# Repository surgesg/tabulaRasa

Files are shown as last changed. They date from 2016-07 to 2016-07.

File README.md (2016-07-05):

# tabulaRasa

The tabulaRasa is a digital wavetable oscillator with voltage control of frequency, waveform selection, 
and the amount of interpolation between waveforms. 
The tabulaRasa consists of two components: a hardware synthesis module which can integrate
into a modular synth system, and a software application which allows the user to create their own custom waveforms. 
These waveforms are then transferred from the computer to the tabulaRasa module through a standard SD card slot.

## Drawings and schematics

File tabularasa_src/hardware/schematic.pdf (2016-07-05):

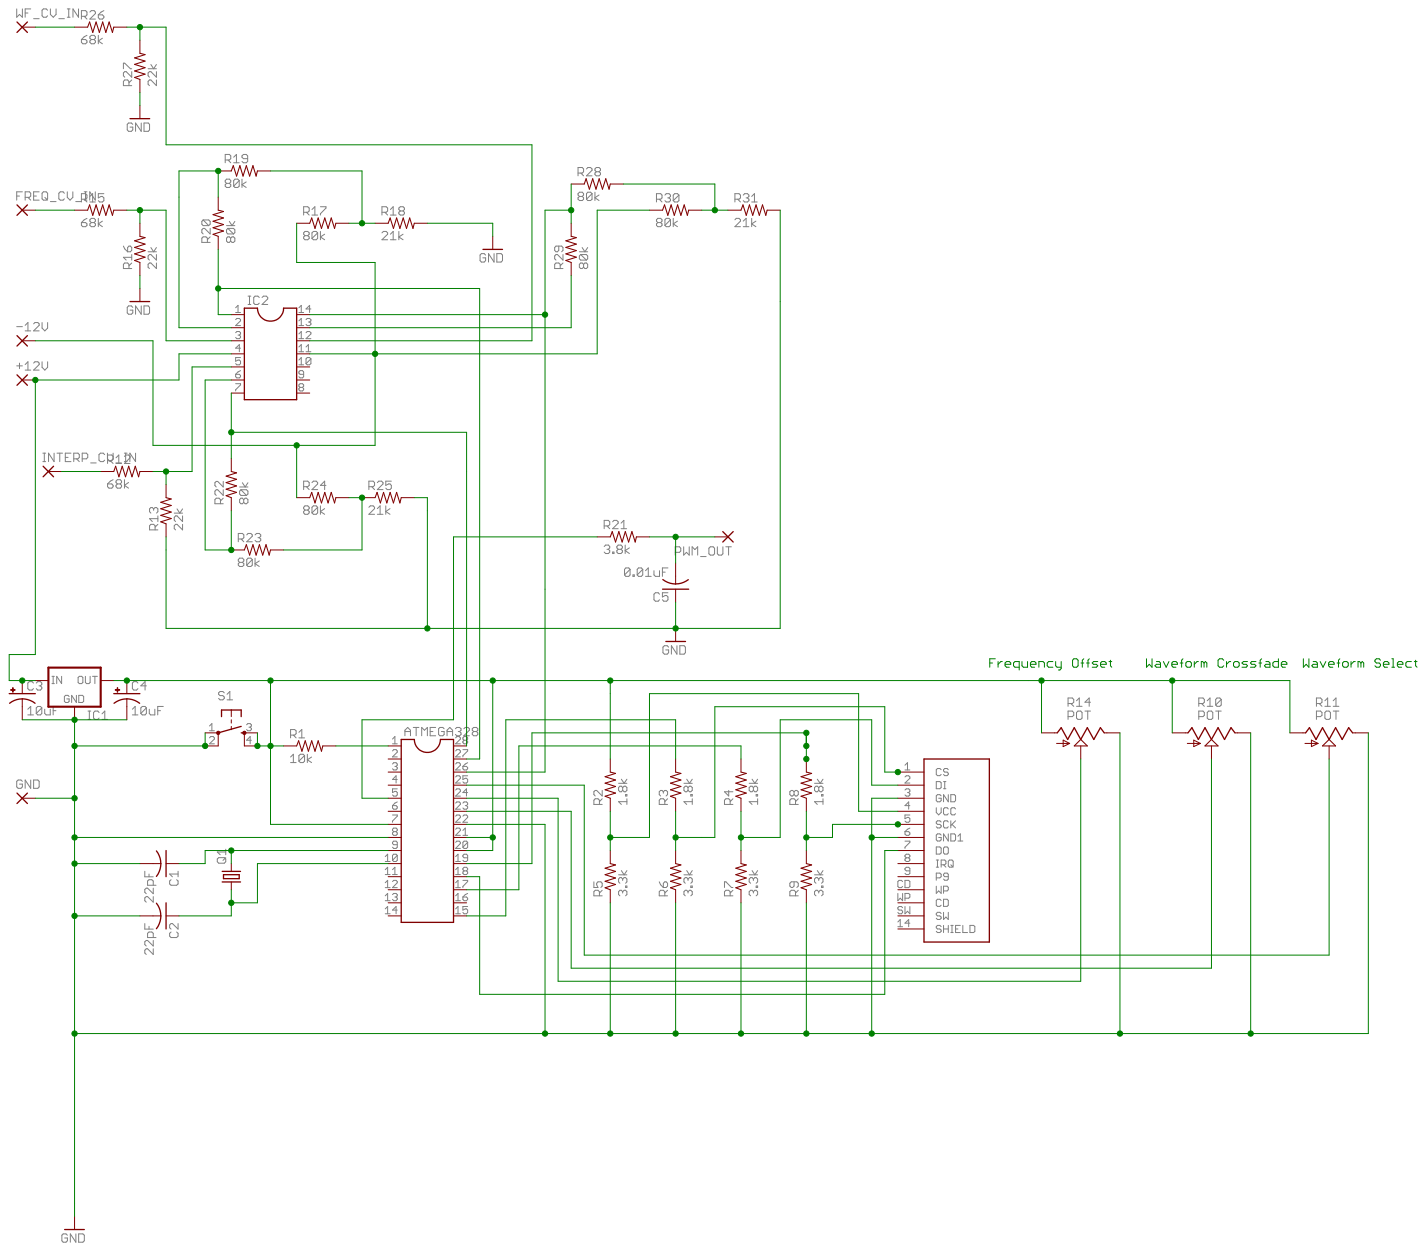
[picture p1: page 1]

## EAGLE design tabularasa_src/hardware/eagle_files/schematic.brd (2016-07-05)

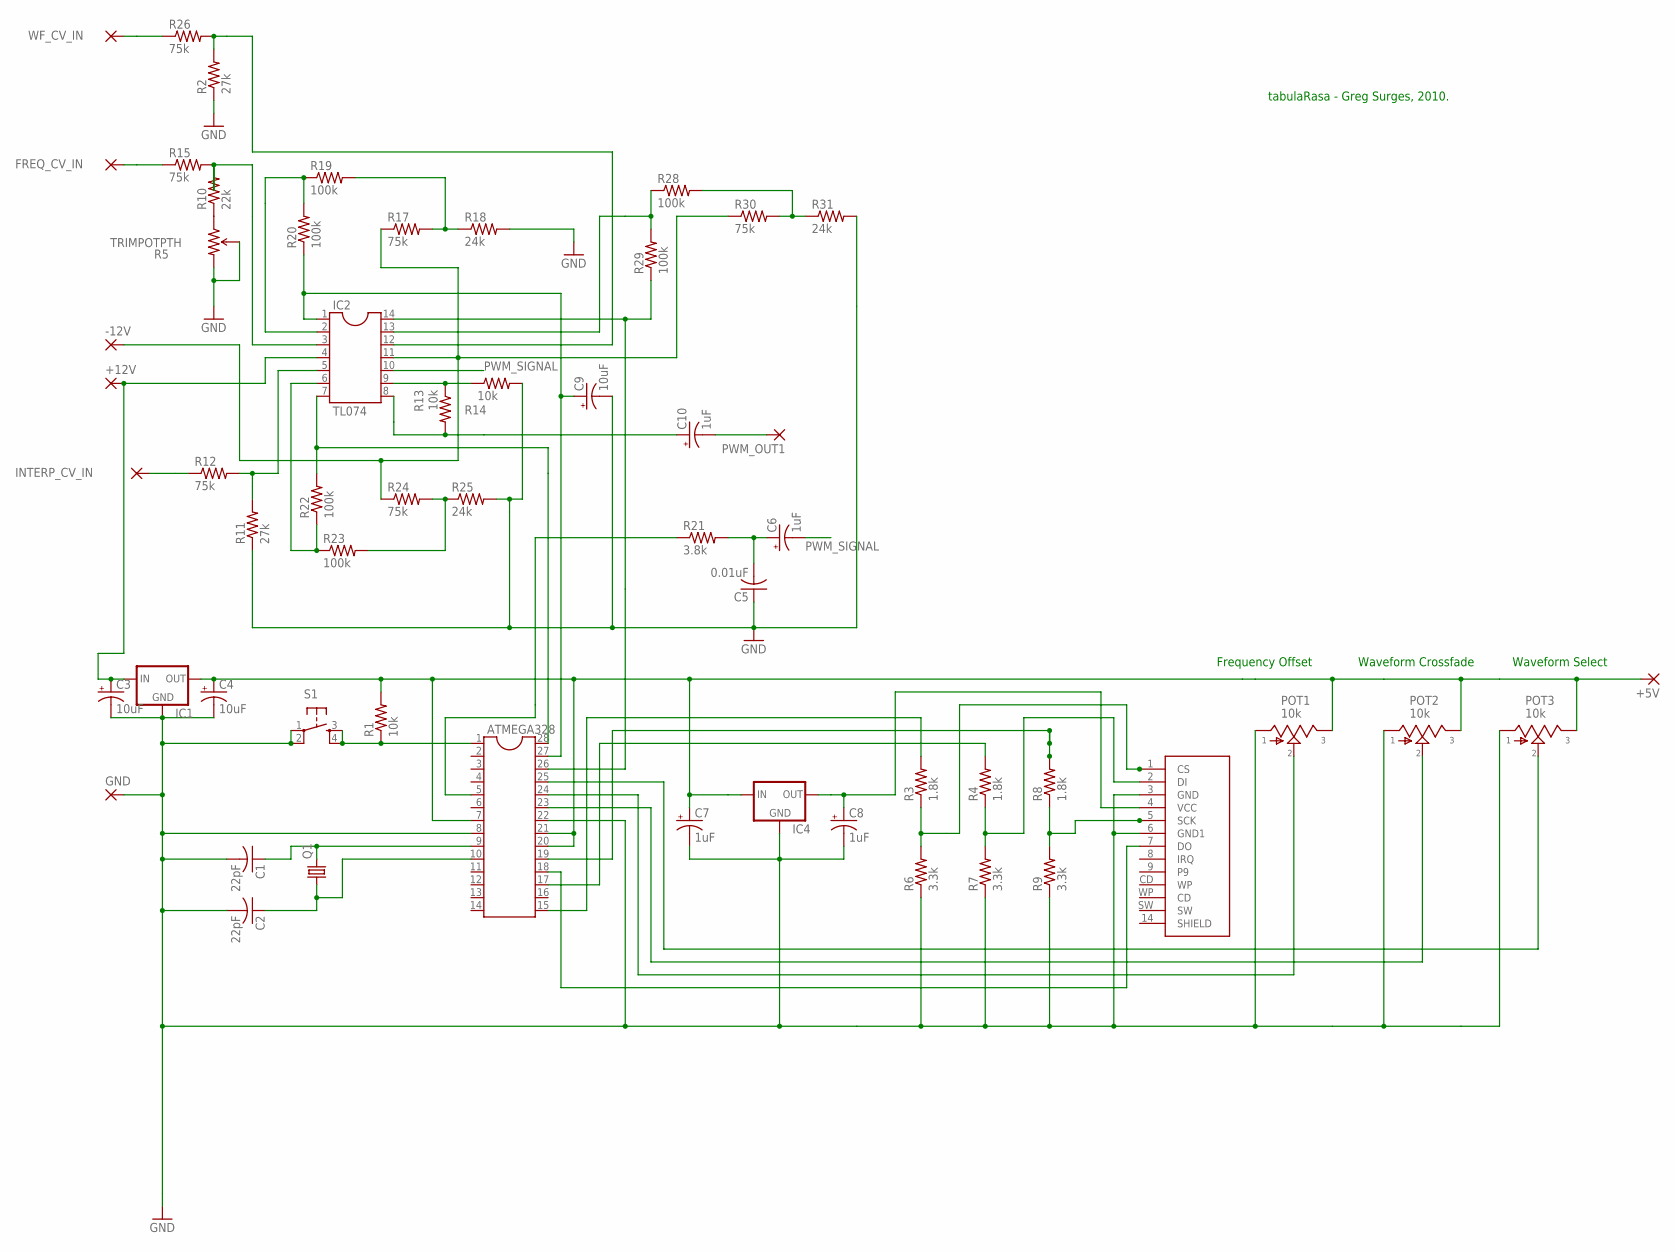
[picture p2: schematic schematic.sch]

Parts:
+5V, +12V: 3,81/1,4
-12V: 3,81/1,4
ATMEGA328: DIL28-3
C1, C2: 22pF; C050-025X075
C3, C4, C9: 10uF; E2,5-6
C5: 0.01uF; C050-025X075
C6, C7, C8, C10: 1uF; E2,5-6
FREQ_CV_IN: 3,81/1,4
GND: 3,81/1,4
IC1: V_REG_78XXSIDE; 78XXL
IC2: TL074; DIL14
IC4: MCP1700INLINE; TO92-INLINE
INTERP_CV_IN: 3,81/1,4
POT1, POT2, POT3: 10k; 16MM-PCB-MOUNT
PWM_OUT1: 3,81/1,4
Q1: CRYSTALHC49US; HC49US
R1, R13, R14: 10k; 0411/12
R2, R11: 27k; 0411/12
R3, R4, R8: 1.8k; 0411/12
R5: TRIMPOTPTH; TRIM_POT_PTH
R6, R7, R9: 3.3k; 0411/12
R10: 22k; 0411/12
R12, R15, R17, R24, R26, R30: 75k; 0411/12
R18, R25, R31: 24k; 0411/12
R19, R20, R22, R23, R28, R29: 100k; 0411/12
R21: 3.8k; 0411/12
S1: TAC_SWITCHPTH; TACTILE-PTH
U$1: SD_CARD_SOCKETSD; SD-MMC_SOCKET-PP
WF_CV_IN: 3,81/1,4

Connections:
GND: ATMEGA328.8, ATMEGA328.22, C1.2, C2.2, C3.-, C4.-, C5.1, C7.-, C8.-, C9.-, GND.1, IC1.GND, IC4.1 (GND), POT1.1, POT2.1, POT3.1, R2.1, R5.2 (WIPER), R5.3 (CW), R6.1, R7.1, R9.1, R11.1, R14.2, R18.2, R25.2, R31.2, S1.1, S1.2, U$1.3 (GND), U$1.6 (GND1)
unnamed: C8.+, IC4.3 (OUT), U$1.4 (VCC)
unnamed: +5V.1, ATMEGA328.7, ATMEGA328.20, ATMEGA328.21, C4.+, C7.+, IC1.OUT, IC4.2 (IN), POT1.3, POT2.3, POT3.3, R1.2
unnamed: R3.1, R6.2, U$1.1 (CS)
unnamed: ATMEGA328.1, R1.1, S1.3, S1.4
unnamed: R4.1, R7.2, U$1.2 (DI)
unnamed: ATMEGA328.9, C1.1, Q1.2
unnamed: ATMEGA328.10, C2.1, Q1.1
unnamed: INTERP_CV_IN.1, R12.1
unnamed: ATMEGA328.18, U$1.7 (DO)
unnamed: R5.1 (CCW), R10.1
unnamed: R8.1, R9.2, U$1.5 (SCK)
unnamed: ATMEGA328.15, R3.2
unnamed: ATMEGA328.24, POT1.2
unnamed: ATMEGA328.17, R4.2
unnamed: ATMEGA328.19, R8.2
unnamed: ATMEGA328.23, POT2.2
unnamed: ATMEGA328.25, POT3.2
unnamed: +12V.1, C3.+, IC1.IN, IC2.4
unnamed: IC2.2, R19.1, R20.2
unnamed: ATMEGA328.28, IC2.7, R22.2
unnamed: IC2.6, R22.1, R23.1
unnamed: FREQ_CV_IN.1, R15.1
unnamed: IC2.9, R13.1, R14.1
unnamed: ATMEGA328.27, C9.+, IC2.1, R20.1
unnamed: R17.2, R18.1, R19.2
unnamed: R28.2, R30.2, R31.1
unnamed: ATMEGA328.5, R21.1
unnamed: C5.2, C6.+, R21.2
unnamed: R23.2, R24.2, R25.1
unnamed: R26.1, WF_CV_IN.1
unnamed: IC2.12, R2.2, R26.2
unnamed: IC2.13, R28.1, R29.2
unnamed: ATMEGA328.26, IC2.14, R29.1
unnamed: -12V.1, IC2.11, R17.1, R24.1, R30.1
unnamed: C10.-, PWM_OUT1.1
unnamed: IC2.3, R10.2, R15.2
unnamed: IC2.5, R11.2, R12.2
OUTPUT: C10.+, IC2.8, R13.2
PWM_SIGNAL: C6.-, IC2.10

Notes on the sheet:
Frequency Offset
Waveform Crossfade
Waveform Select
tabulaRasa - Greg Surges, 2010.

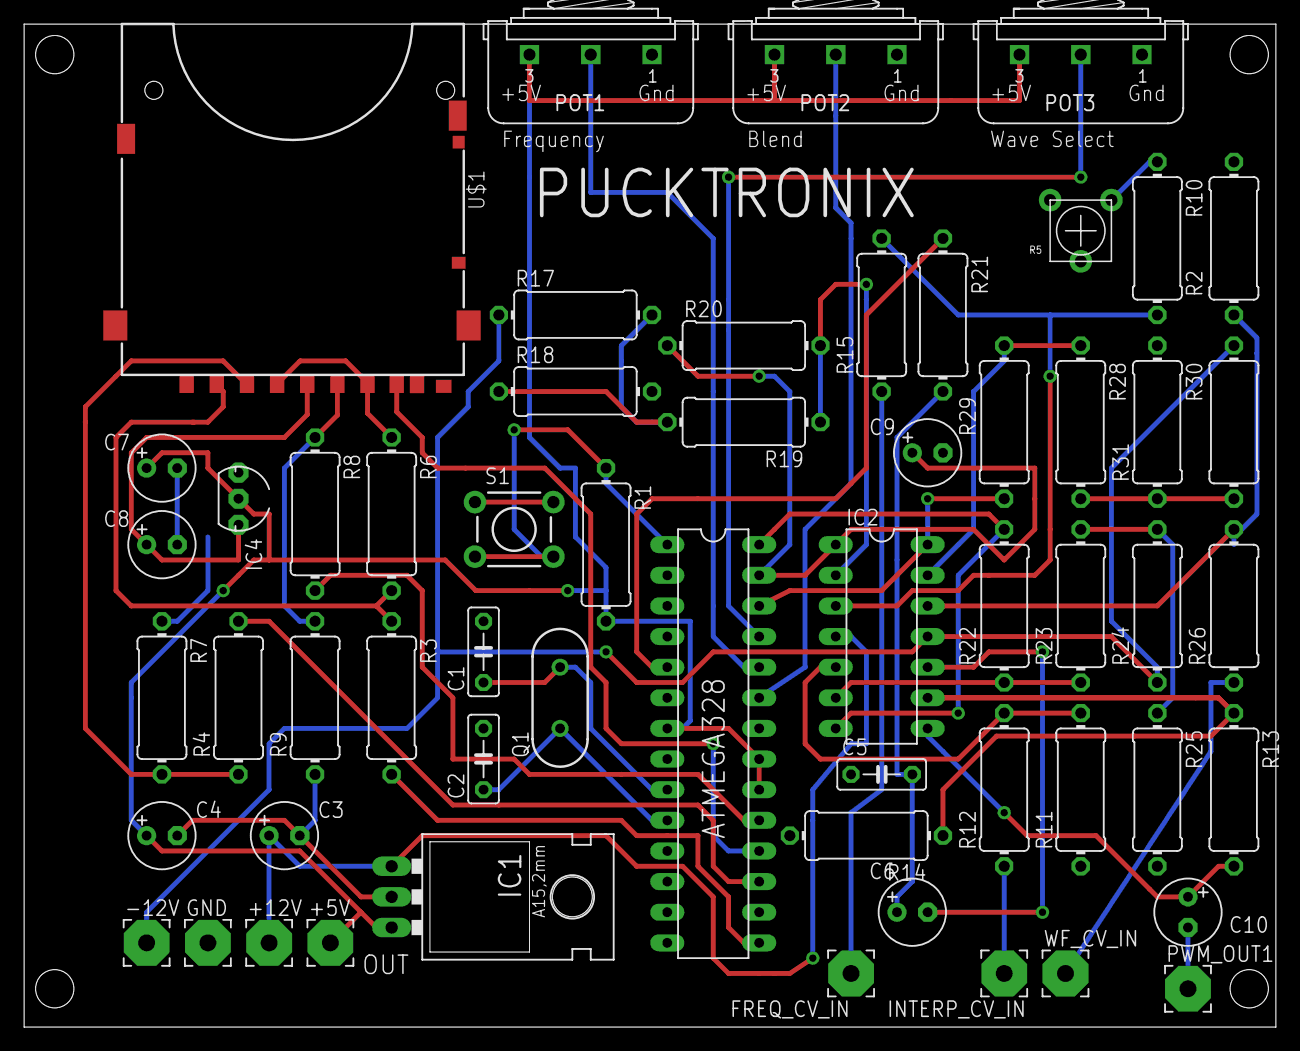
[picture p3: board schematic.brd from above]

Board: 2 copper layers, 103.8 x 83.2 mm, 57 parts (0 on the bottom side), 40 nets.

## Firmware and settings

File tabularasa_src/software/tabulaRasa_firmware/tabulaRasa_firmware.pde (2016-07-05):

/*************************************************
 * tabulaRasa_Arduino_PWM.pde
 * last updated 3.12.2011 - greg surges surgesg@gmail.com
 * 
 * atmega328 (w/ arduino bootloader) mcu code for use in tabulaRasa wavetable oscillator
 * 
 * reads "data.dat" from sd card - produced by tabulaRasa Editor Software
 * 
 * some code borrowed from Adrian Freed
 * 
 * todo: 
 * continued commenting
 * internal pullup / down resistors on analog pins
     
    This file is part of tabulaRasa.

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
    You should have received a copy of the GNU General Public License
    along with tabulaRasa.  If not, see <http://www.gnu.org/licenses/>.
*/
 
 *************************************************/

#include <avr/io.h>
#include <avr/interrupt.h>

#include <SD.h>

#define PWM_PIN       3
#define PWM_VALUE_DESTINATION     OCR2B
#define PWM_INTERRUPT TIMER2_OVF_vect

Sd2Card card;
SdVolume volume;
SdFile root;
SdFile file;

/*** variables from Adrian Freed ***/
const unsigned int LUTsize = 1<<8; 
const int timerPrescale=1<<9;
const int fractionalbits = 16; 
uint8_t predivide = 8;
/******************************/

byte waveform[256 * 2]; // allocate RAM to store the currently used waveforms
int8_t waveformSlot = 0; // the current waveform, corresponding to the slots in the Editor App
int8_t previousWaveformSlot = 0;
byte finalWaveform[256]; // the composite waveform, after computing crossfade 

int8_t outputvalue = 0; // the sample written out to PWM
float frequency; // oscillation frequency in Hz.
int8_t counter = 0; // limit the rate at which slot and crossfade input adc is read

float frequencyInputs = 0;
float freqCV = 0;
int slotInputs = 0;
float slotCV = 0;
float fadeInputs = 0;
float fadeCV = 0;
float midpoint = 0;
float range = 0;

// store error strings in flash to save RAM
#define error(s) error_P(PSTR(s))
void error_P(const char* str) {
  PgmPrint("error: ");
  SerialPrintln_P(str);
  if (card.errorCode()) {
    PgmPrint("SD error: ");
    Serial.print(card.errorCode(), HEX);
    Serial.print(',');
    Serial.println(card.errorData(), HEX);
  }
  while(1);
}

struct oscillator
{
  uint32_t phase;
  int32_t phase_increment;
} 
o1;

/*** following 2 functions from Adrian Freed ***/
unsigned long phaseinc(float frequency_in_Hz)
{
  return LUTsize *(1l<<fractionalbits)* frequency_in_Hz/(F_CPU/timerPrescale);
}

void initializeTimer() {
  TCCR2A = _BV(COM2B1)  | _BV(WGM21) | _BV(WGM20);
  TCCR2B = _BV(CS20);
  TIMSK2 = _BV(TOIE2);
  pinMode(PWM_PIN,OUTPUT);
}
/**********************************************/


void setup()
{
  pinMode(A0, INPUT);
  pinMode(A1, INPUT);
  digitalWrite(A1, HIGH);
  pinMode(A2, INPUT);
  pinMode(A3, INPUT);
  pinMode(A4, INPUT);
  digitalWrite(A4, HIGH);
  pinMode(A5, INPUT);
  if (!card.init(SPI_FULL_SPEED, 9)) error("card.init failed");
  if (!volume.init(&card)) error("volume.init failed");
  if (!root.openRoot(&volume)) error("openRoot failed"); 
  if (file.open(&root, "data.dat", O_READ)) {
    //  Serial.println("Opened data.dat");
  }
  file.read(waveform, 256 * 2);
  o1.phase = 0;
  o1.phase_increment = 0;
  initializeTimer();
}

void loop() {
  /*****************************************************************************
   * frequency is modulated by both pot and cv input, which are summed - each covering half the potential range
   * necessary to do it this way to maintain v/octave control of pitch.
   *****************************************************************************/
  analogRead(A1); // toss this value for accuracy
  frequencyInputs = analogRead(A1) / 102.3;
  analogRead(A4); // toss this value for accuracy
  frequencyInputs += analogRead(A4) / 102.3;
  
  frequencyInputs = pow(2, frequencyInputs); // v/octave pitch
  frequency = (frequency * 0.8) + (frequencyInputs * 0.2); // compute a moving average, to minimize freq jitter
  o1.phase_increment = phaseinc(frequency);

  // the other controls are only read every 50th cycle through loop() because they are less frequency dependent
  // hopefully this allows for a higher rate of FM

  if(counter >= 50){
    /*****************************************************************************  
     * the midpoint of the waveform select is set by the potentiometer.
     * the potentiometer setting also establishes the range that the cv input is allowed to cover.
     * when the pot is set in the middle, the cv in swings the whole range (0 - 63), otherwise it is limited to a smaller range.
     * this keeps the waveform value value constrained to the range 0 - 63, while still allowing both the pot and the cv input
     * to cover the entire range 
     *****************************************************************************/
    midpoint = analogRead(A2) * 0.0009775; // knob 0 - 1
    if(midpoint <= 0.5) {
      range = midpoint;
    } else {
      range = (1 - midpoint) * -1;		
    }
    slotCV = analogRead(A3) * 0.0009775; // 0 - 1
    slotCV = (slotCV * 2) - 1; // -1 to +1
    waveformSlot = int((midpoint + (slotCV * range)) * 32) * 2;
    if(waveformSlot != previousWaveformSlot){
      file.seekSet(waveformSlot * 256); 
      cli();
      file.read(waveform, 256 * 2);
      sei();
      previousWaveformSlot = waveformSlot;
    }
    /*****************************************************************************  
     * the midpoint of the crossfade is set by the potentiometer.
     * the potentiometer setting also establishes the range that the cv input is allowed to cover.
     * when the pot is set in the middle, the cv in swings the whole range (0 - 1), otherwise it is limited to a smaller range.
     * this keeps the crossfade value constrained to the range 0.0 - 1.0, while still allowing both the pot and the cv input
     * to cover the entire range 
     *****************************************************************************/
    midpoint = analogRead(A0) * 0.0009775; // 0 - 1
    if(midpoint <= 0.5) {
      range = midpoint;
    } else {
      range = (1 - midpoint) * -1;
    }
    fadeCV = analogRead(A5) * 0.0009775; // 0 - 1
    fadeCV = (fadeCV * 2) - 1; // -1 to +1
    fadeInputs = midpoint + (fadeCV * range);
    for(int i = 0; i < 256; ++i){
      finalWaveform[i] =  (waveform[i] * fadeInputs) + (waveform[i + 256] * (1 - fadeInputs)); 
    }
    counter = 0;
  }
  ++counter;
}

SIGNAL(PWM_INTERRUPT)
{
  PWM_VALUE_DESTINATION = outputvalue; 
  outputvalue = (finalWaveform[((o1.phase>>16)%LUTsize)]); 
  o1.phase = o1.phase + o1.phase_increment;
}

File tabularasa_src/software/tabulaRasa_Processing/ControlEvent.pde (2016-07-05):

/*
    ControlEvent.pde
    Ver 1.02
    Jan 28 2011
    greg surges
    surgesg@gmail.com
    http://www.gregsurges.com/
     
    This file is part of tabulaRasa.

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
    You should have received a copy of the GNU General Public License
    along with tabulaRasa.  If not, see <http://www.gnu.org/licenses/>.
*/

public void controlEvent(ControlEvent theEvent) {  //button events
//--------------------------------------------------
//Control Ids:
//memory slots (0-63)
//interpolation (64-71)
//sliders (72-88)
//--------------------------------------------------
  int Id = theEvent.controller().id();
  if(Id >=0 & Id < 64) {  //buttons 0-63 Memory slots
    currentSlot = Id;
    interpType = slotInterp[currentSlot];  //get current interpType
    slotStatus[currentSlot] = true;
  } 
  else if(Id >= 64 & Id < 70) {  //buttons 64-71 interpolations
    interpType = Id - 64;
  }
  else if (Id == 70) {  //Button 62 Samples
    interpType = Id - 64;
    loadSample();
    }  
   else if(Id == 71) {  //Harmonics
      if(interpType < 7){
        clear_to_harmonics();
//        println(Id);
    }
    interpType = Id - 64;
  }
  else if(Id >= 72 & Id < 89) {  //buttons 72-88 slider controls -- nothing to do
  }
  slotInterp[currentSlot] = interpType;  //keep interp with slot values
  changedSamples = true;
}
void Clear() {
    interpType = 0;  
    clear_to_bands();
}

void rspkr() {
    volSlider.setValue(1);
}

void lspkr() {
    volSlider.setValue(0);
}
void About() {
    setAbout = true;
}

void keyPressed() {
  if(key == 'c') {
    copyWave();
  }
  else if(key == 'v') {
    pasteWave();
  }
  else if(key == 's') {
    Save();
  }
  else if(key == 'l') {
    Load();
  }
  else if(key == 'a') {
    if(volSlider.value() > 0) {
        volSlider.setValue(0);
    }
    else {
        volSlider.setValue(1);
    }
   }
  }
 void mousePressed() {
   setAbout = false;
 }

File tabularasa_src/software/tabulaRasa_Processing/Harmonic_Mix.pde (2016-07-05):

/*
    Harmonic_Mix.pde
    Ver 1.02
    Jan 28 2011
    greg surges
    surgesg@gmail.com
    http://www.gregsurges.com/
     
    This file is part of tabulaRasa.

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
    You should have received a copy of the GNU General Public License
    along with tabulaRasa.  If not, see <http://www.gnu.org/licenses/>.
*/

void harmonicMix(){
  noStroke();
  fill(255);
  for(int num =0;num < 16;num++) {  //display harmonic labels
    labelName = Integer.toString(num+1) + "F";
    text(labelName, num * 25+5,412);
  }
  float maximum = 0;
  float minimum = 0;
    for(int i = 0; i < 256; ++i) {
    data[i] = 0;
  }
  if(sliderData[16 * (currentSlot)] == 127) {
    }
  float tempDataArray[] = new float[256];
  float sineArray[][] = new float[16][256];
  int currentSample = 0;
  int nextSample = 0;
  for(int i = 0; i < 16; ++i) {
    sliderData[i + (16 * (currentSlot))] = (int)sliders[i].value();
  }
//calculate the sine waves and populate the arrays
  for(int harmonic = 0; harmonic < 16; ++harmonic) {
    for(int i = 0; i < 256; ++i) {
      sineArray[harmonic][i] = (((sliderData[harmonic + (16 * (currentSlot))]) * sin((1 + harmonic) * TWO_PI/256 * i)));
      tempDataArray[i] += sineArray[harmonic][i]; //sum harmonics
      if(tempDataArray[i] > maximum){  //look for highest level
        maximum = tempDataArray[i];
      }
      if(tempDataArray[i] < minimum){  //look for lowest level
        minimum = tempDataArray[i];
      }
    }
  }
//normalize the waveform
  for(int i = 0; i < 256; ++i) {
    tempDataArray[i] = map(tempDataArray[i],minimum,maximum,15,240);  //( maximum=peak  15=lower boundary 240=upper boundary)
    data[i] = byte(tempDataArray[i]);
    file[i + (256 * (currentSlot))] = data[i];
  }
  slotStatus[currentSlot] = true;
}

//reset the display for harmonics
void clear_to_harmonics(){  //set display to zero baseline slider1 to max
  for(int i = 0; i < 16; ++i) {
    sliderData[i + (16 * (currentSlot))] = 0;
  }
  sliderData[16 * (currentSlot)]=255;
  loadSliders();
  slotStatus[currentSlot] = false;
}

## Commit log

2016-07-05 added hardware files
    [schematic.brd, schematic.sch]
2016-07-05 added schematic

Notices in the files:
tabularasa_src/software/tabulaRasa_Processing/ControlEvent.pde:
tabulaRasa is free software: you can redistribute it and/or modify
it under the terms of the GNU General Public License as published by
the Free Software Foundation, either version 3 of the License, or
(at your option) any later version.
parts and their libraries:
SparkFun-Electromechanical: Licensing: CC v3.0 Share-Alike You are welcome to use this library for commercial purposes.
